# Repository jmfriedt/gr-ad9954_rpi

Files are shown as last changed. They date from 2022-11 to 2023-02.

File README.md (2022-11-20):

# gr-ad9954_rpi

Daughter board for the Raspberry Pi 3 or 4 fitted with an Analog Devices AD9954 Direct 
Digital Synthesizer.

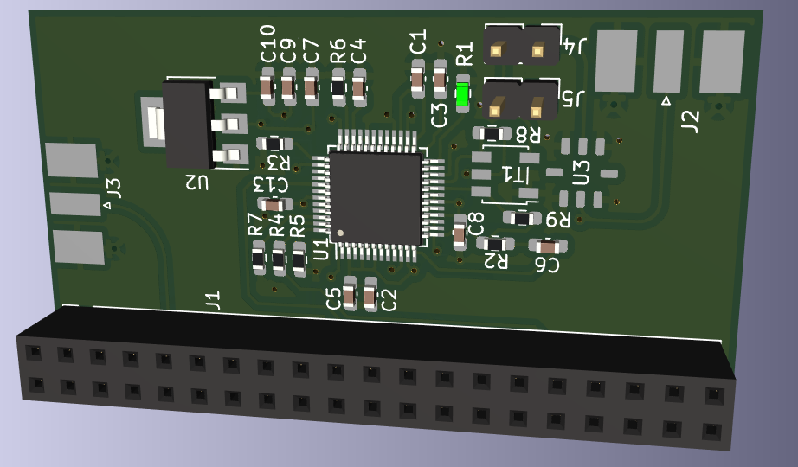
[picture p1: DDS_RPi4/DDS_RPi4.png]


KiCAD 6 schematic and board are provided.

Mechanical analysis using FreeCAD of the board compatibility with the RPi4:

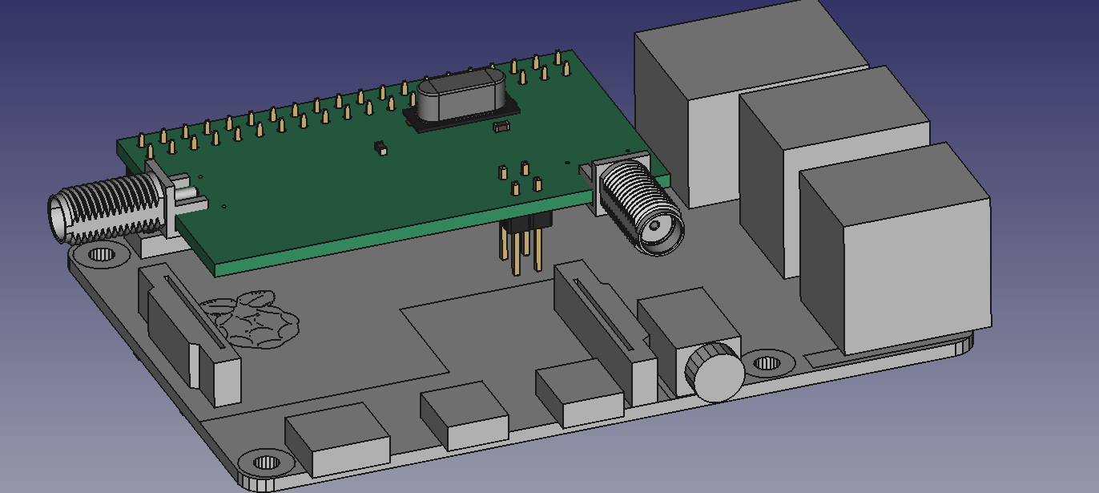
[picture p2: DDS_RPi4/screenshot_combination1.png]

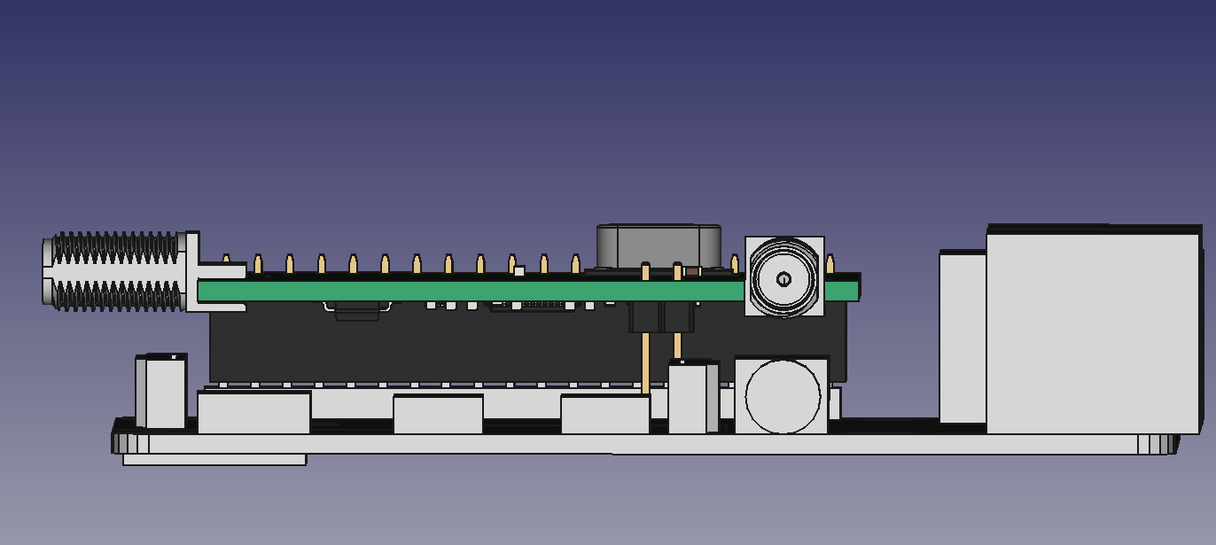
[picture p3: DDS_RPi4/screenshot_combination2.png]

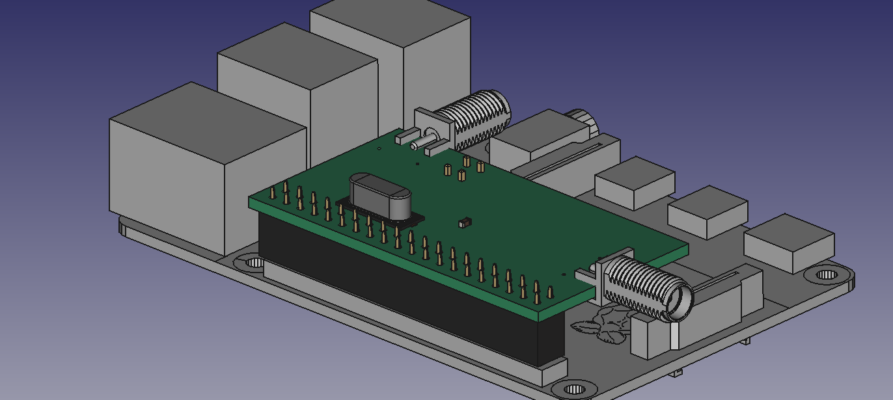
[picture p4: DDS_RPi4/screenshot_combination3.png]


The Python 3 script ``ad9954.py`` was used to demonstrate proper operation of the board:

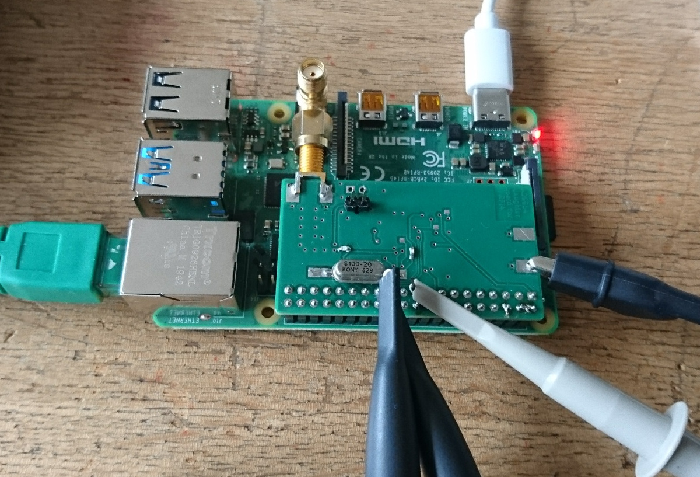
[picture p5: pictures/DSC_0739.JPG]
 
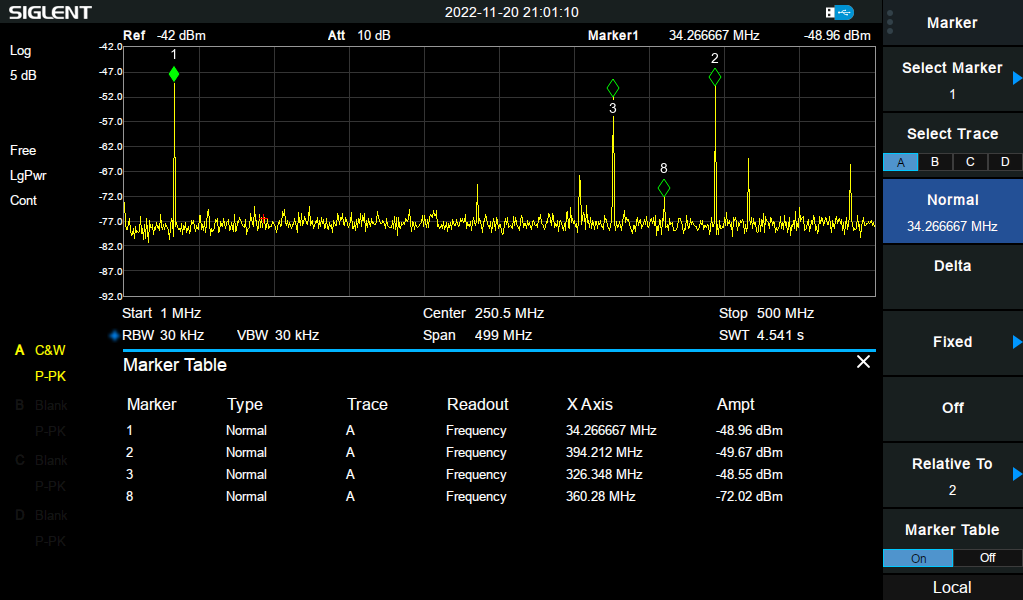
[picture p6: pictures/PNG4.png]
 
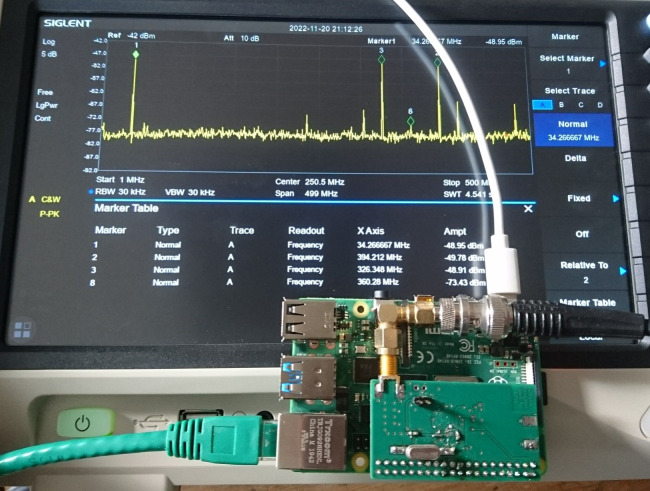
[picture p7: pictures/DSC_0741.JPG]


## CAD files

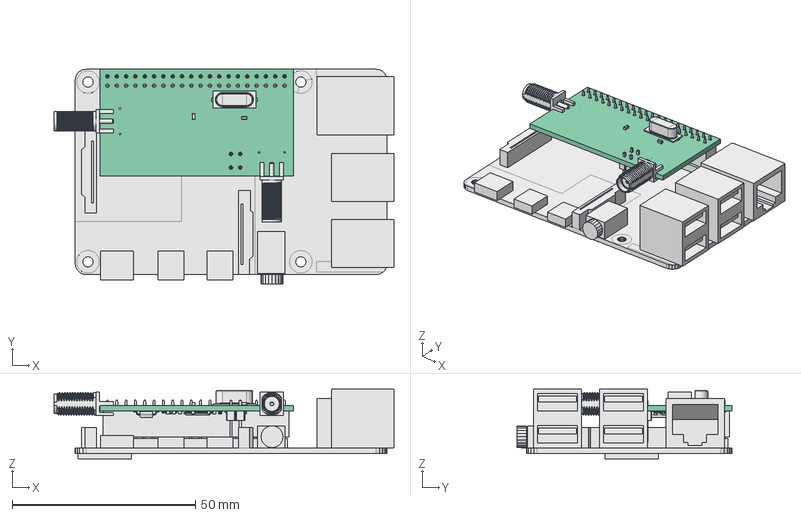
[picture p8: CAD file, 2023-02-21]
DDS_RPi4/combinaison.FCStd
92.7 x 58.7 x 19.0 mm
Pcb_2ad0
J5_PinHeader_1x02_P254mm_Vertical_ec923658a7ff x 2
C5_C_0603_1608Metric_8c4036a43880 x 13
U1_TQFP_48_1EP_7x7mm_P05mm_735b334df305
R4_R_0603_1608Metric_d5d691ccd8b9 x 9
J1_PinSocket_2x20_P254mm_Vertical_10f443b71191
U2_SOT_223_40ddeac8b708
Y2_Crystal_SMD_HC49-SD_2c9015c02a45
Raspberry Pi 4 B

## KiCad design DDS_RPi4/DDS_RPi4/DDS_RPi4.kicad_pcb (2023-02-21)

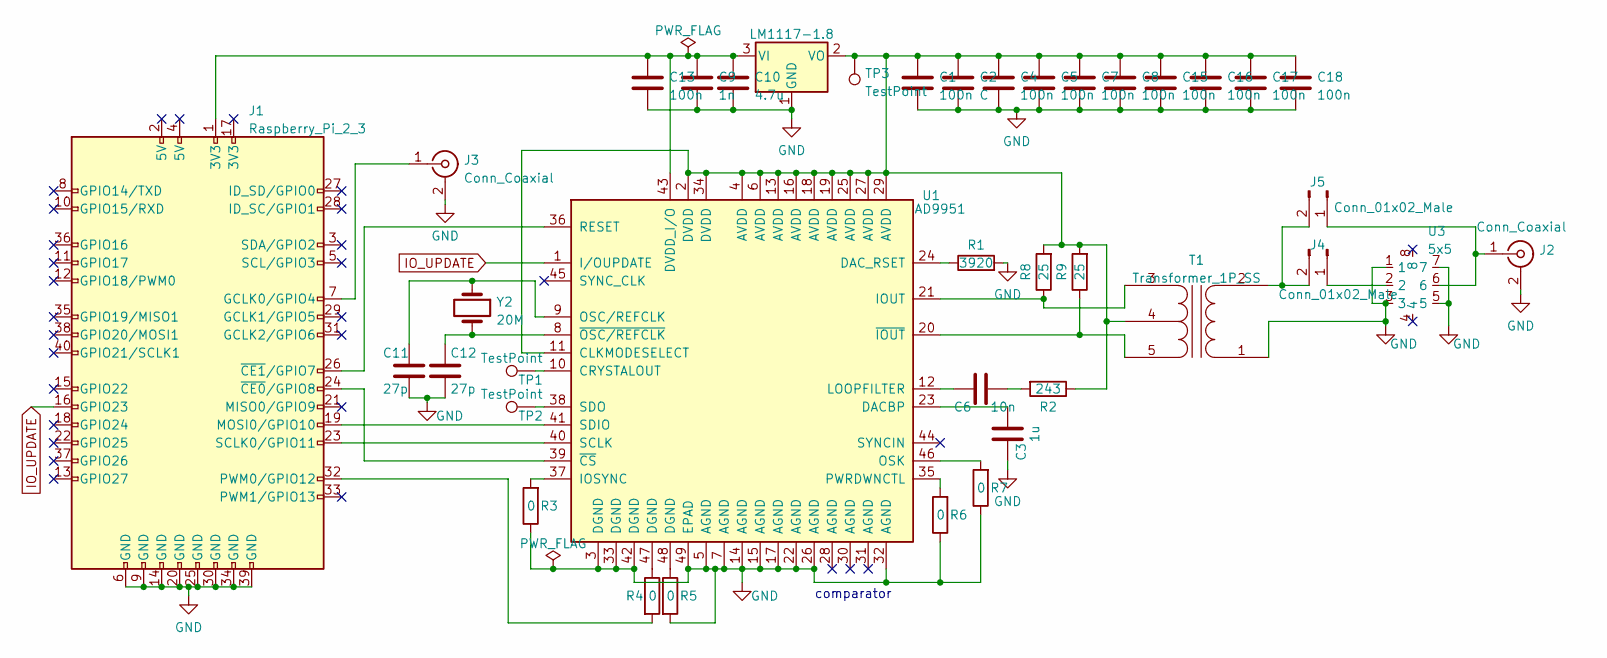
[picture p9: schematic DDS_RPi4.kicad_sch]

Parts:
C1, C4, C5, C7, C8, C13, C15, C16, C17, C18: 100n; C_0603_1608Metric_Pad1.08x0.95mm_HandSolder
C2: C; C_0603_1608Metric_Pad1.08x0.95mm_HandSolder
C3: 1u; C_0603_1608Metric_Pad1.08x0.95mm_HandSolder
C6: 10n; C_0603_1608Metric_Pad1.08x0.95mm_HandSolder
C9: 1n; C_0603_1608Metric_Pad1.08x0.95mm_HandSolder
C10: 4.7u; C_0603_1608Metric_Pad1.08x0.95mm_HandSolder
C11, C12: 27p; C_0603_1608Metric_Pad1.08x0.95mm_HandSolder
J1: Raspberry_Pi_2_3; PinSocket_2x20_P2.54mm_Vertical
J2, J3: Conn_Coaxial; SMA_Molex_73251-2120_EdgeMount_Horizontal
J4, J5: Conn_01x02_Male; PinHeader_1x02_P2.54mm_Vertical
R1: 3920; R_0603_1608Metric_Pad0.98x0.95mm_HandSolder
R2: 243; R_0603_1608Metric_Pad0.98x0.95mm_HandSolder
R3, R4, R5, R6, R7: 0; R_0603_1608Metric_Pad0.98x0.95mm_HandSolder
R8, R9: 25; R_0603_1608Metric_Pad0.98x0.95mm_HandSolder
T1: Transformer_1P_SS; Transformer_MACOM_SM-22
TP1, TP2, TP3: TestPoint; TestPoint_Pad_1.0x1.0mm
U1: AD9951; TQFP-48-1EP_7x7mm_P0.5mm_EP3.5x3.5mm
U2: LM1117-1.8; SOT-223-3_TabPin2
U3: 5x5
Y2: 20M; Crystal_SMD_HC49-SD_HandSoldering

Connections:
GND: C1.2, C2.2, C3.1, C4.2, C5.2, C7.2, C8.2, C9.2, C10.2, C11.2, C12.2, C13.2, C15.2, C16.2, C17.2, C18.2, J1.6 (GND), J1.9 (GND), J1.14 (GND), J1.20 (GND), J1.25 (GND), J1.30 (GND), J1.34 (GND), J1.39 (GND), J2.2 (Ext), J3.2 (Ext), R1.2, R3.1, R5.2, R6.1, R7.1, T1.1 (AA), U1.3 (DGND), U1.5 (AGND), U1.7 (AGND), U1.14 (AGND), U1.15 (AGND), U1.17 (AGND), U1.22 (AGND), U1.26 (AGND), U1.32 (AGND), U1.33 (DGND), U1.42 (DGND), U1.49 (EPAD), U2.1 (GND), U3.1, U3.3, U3.5, U3.7
IO_UPDATE: J1.16 (GPIO23), U1.1 (I/OUPDATE)
unnamed: C1.1, C2.1, C4.1, C5.1, C7.1, C8.1, C15.1, C16.1, C17.1, C18.1, R2.1, R8.2, R9.2, T1.4 (SC), TP3.1, U1.2 (DVDD), U1.4 (AVDD), U1.6 (AVDD), U1.11 (CLKMODESELECT), U1.13 (AVDD), U1.16 (AVDD), U1.18 (AVDD), U1.19 (AVDD), U1.25 (AVDD), U1.27 (AVDD), U1.29 (AVDD), U1.34 (DVDD), U2.2 (VO)
unnamed: C3.2, U1.23 (DACBP)
unnamed: C6.1, U1.12 (LOOPFILTER)
unnamed: C6.2, R2.2
unnamed: C9.1, C10.1, C13.1, J1.1 (3V3), U1.43 (DVDD_I/O), U2.3 (VI)
unnamed: C11.1, U1.9 (OSC/REFCLK), Y2.1
unnamed: C12.1, U1.8 (~OSC/REFCLK), Y2.2
unnamed: J1.7 (GCLK0/GPIO4), J3.1 (In)
unnamed: J1.19 (MOSI0/GPIO10), U1.41 (SDIO)
unnamed: J1.23 (SCLK0/GPIO11), U1.40 (SCLK)
unnamed: J1.24 (~CE0/GPIO8), U1.39 (~CS)
unnamed: J1.26 (~CE1/GPIO7), U1.36 (RESET)
unnamed: J1.32 (PWM0/GPIO12), R4.2
unnamed: J2.1 (In), J5.1, U3.6
unnamed: J4.1, U3.2
unnamed: J4.2, J5.2, T1.2 (AB)
unnamed: R1.1, U1.24 (DAC_RSET)
unnamed: R3.2, U1.37 (IOSYNC)
unnamed: R4.1, U1.47 (DGND)
unnamed: R5.1, U1.48 (DGND)
unnamed: R6.2, U1.35 (PWRDWNCTL)
unnamed: R7.2, U1.46 (OSK)
unnamed: R8.1, T1.3 (SA), U1.21 (IOUT)
unnamed: R9.1, T1.5 (SB), U1.20 (~IOUT)
unnamed: TP1.1, U1.10 (CRYSTALOUT)
unnamed: TP2.1, U1.38 (SDO)

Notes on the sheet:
comparator

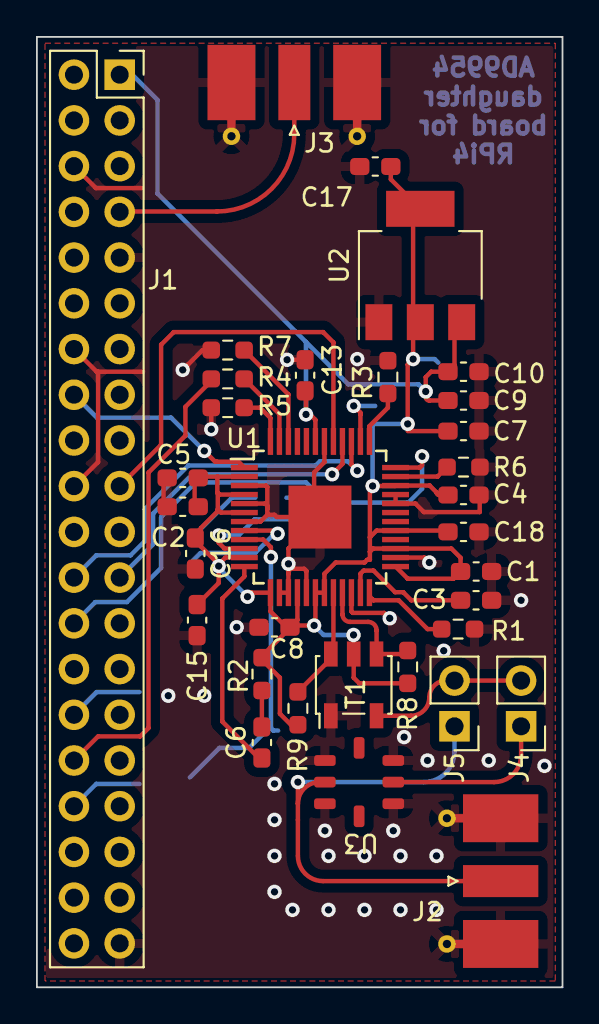
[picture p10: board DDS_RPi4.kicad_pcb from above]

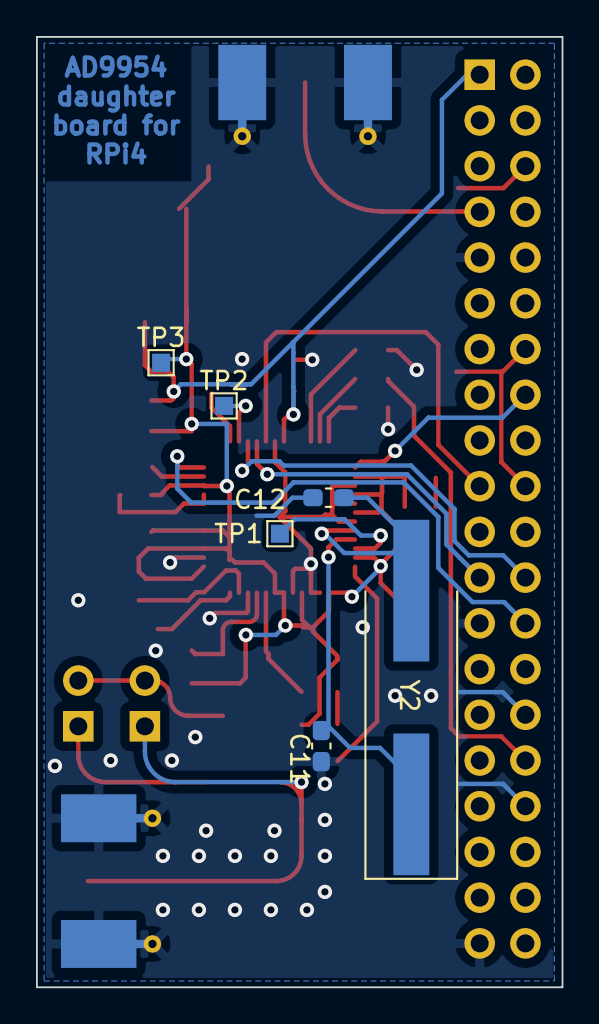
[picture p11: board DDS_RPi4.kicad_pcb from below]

Board: 2 copper layers, 29.2 x 52.8 mm, 39 parts (6 on the bottom side), 28 nets.

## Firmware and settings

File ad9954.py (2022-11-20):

# Datashet AD9954 p.23: SPI CK rest state=0, change on falling edge => mode 0
# GPIO12 -> 47
# GPIO23 -> IO_UPDATE
import time
import spidev
import pigpio

bus = 0       # SPI0
device = 0    # CS#
spi = spidev.SpiDev()
spi.open(bus, device)
spi.max_speed_hz = 1000000
spi.mode = 0

pi=pigpio.pi()
pi.set_mode(12,pigpio.OUTPUT)
pi.write(12, 0)  # PS0 low

pi.set_mode(23,pigpio.OUTPUT)
pi.write(23, 0)  # IO_UPDATE low

pi.set_mode( 7,pigpio.OUTPUT)
pi.write( 7, 0)  # reset low
time.sleep(0.01)
pi.write( 7, 1)  # reset hi
time.sleep(0.01)
pi.write( 7, 0)  # reset low

CFR1=[0x00, 0x00, 0x00, 0x00, 0x40]; # CFR1 disable comparator
CFR2=[0x01, 0xC4, 0x02, 0x94];       # CFR2 REFCLK Multiplier 0xA0=x20 => 400 MHz bits 3-7, 02 for VCO = 400 MHz
                                     #                        0x90=x18 => 360 MHz
ASF =[0x02, 0x04, 0x55];             # Auto Ramp Rate Speed control=11 (ASF: Amplitude Scale Factor)
ARR =[0x03, 0xff];                   # ARR      Amplitude Ramp Rate register
POW0=[0x05, 0x00, 0x00];             # POW0 PHASE Offset World <13:0>  Not Used= 00
FTW1=[0x06, 0x2C, 0x8B, 0x43, 0x95]; # FTW1  Frequency Tuning Word
# FTW0=[0x04, 0x17, 0x77, 0x77, 0x77]; # FTW0 Frequency tuning World dec2hex(floor(33/360*2^32))
FTW0=[0x04, 0x18, 0x2d, 0x82, 0xd8]; # FTW0 Frequency tuning World dec2hex(floor(34/360*2^32))

spi.xfer2(CFR1)
spi.xfer2(CFR2)
spi.xfer2(ASF)
spi.xfer2(ARR)
spi.xfer2(POW0)
spi.xfer2(FTW1)
spi.xfer2(FTW0)
pi.write(23, 1)  # IO_UPDATE
time.sleep(0.01)
pi.write(23, 0)
